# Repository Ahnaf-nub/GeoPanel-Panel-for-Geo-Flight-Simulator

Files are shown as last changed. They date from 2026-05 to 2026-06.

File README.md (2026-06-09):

Real-time flight telemetry display for GeoFS flight simulator using a Raspberry Pi Pico with TFT display, rotary encoder, and LED indicator.
Demo Link: https://youtu.be/hnZdgzygMNU

Use the Tampermonkey extension to add the geofs-telemetry-sender.js script. Follow the below for guidance:
Screenshot (104)
From Extensions click on Tampermonkey and click on "Create a new script".
Screenshot (106)
Then Paste the javascript code in here and save it!

## Bill of Materials (BOM)

| Part # | Component | Qty | Description |
|---|---|-----|---|
| 1 | Raspberry Pi Pico | 1 | Microcontroller
| 2 | ST7735 128x160 TFT Display | 1 | TFT Display | 1.8 inch |
| 3 | Push Button | 1 | User Input | Main button |
| 5 | Rotary Encoder | 1 | Parameter setting User Input | EC11 |

## Wiring Connections



### TFT Display (SPI)
- **MOSI** → GP27 (SPI TX)
- **SCK** → GP26 (SPI Clock)
- **CS** → GP21
- **DC** → GP19
- **RST** → GP18
- **VCC** → 3V3
- **GND** → GND

### LED
- **Onboard Green LED** → GP25

### Push Buttons
- **Main Button** → GP0
  
### Rotary Encoder
- **CLK (A)** → GP10
- **DT (B)** → GP11 
- **SW** → GP28 
- **+** → 3V3
- **GND** → GND

### Hardware Case

3D printed enclosure designed using fusion 360 (avionics_1.8inch.3mf) CAD model.

### System Architecture

```text
GeoFS Simulator → Tampermonkey Telemetry Script → Serial/Web Communication → Raspberry Pi Pico → TFT Display / LED / Inputs
```
There are 3 Tabs on the display:
1. FLT — Displays Flight data (IAS, ALT, VS, HDG, Pitch, Roll, etc.)
2. NAV — Displays Navigation information (Waypoint, Course, Bearing, Distance)
3. ADA — Displays Aircraft data & alerts (AOA, G-Load, Engine, Wind, Warnings)
   
### UI Design
Cockpit-style avionics layout
Typeface: Airbus B612 font used for all cockpit text rendering

## Dependencies

```ini
lib_deps = 
    adafruit/Adafruit ST7735 and ST7789 Library@^1.11.0
    adafruit/Adafruit NeoPixel
```

## Features

- Real-time flight data display (pitch, roll, heading, altitude, airspeed)
- G-load and stall/overspeed and other warning indicators
- Autopilot status display
- Rotary encoder for autpilot parameters adjustment
- LED status indicator
- System data visualization

## Future Plans

Currently working on adding potentiometer for thrust control. Also, will be adding a 1.28 inch round display to add radar system!

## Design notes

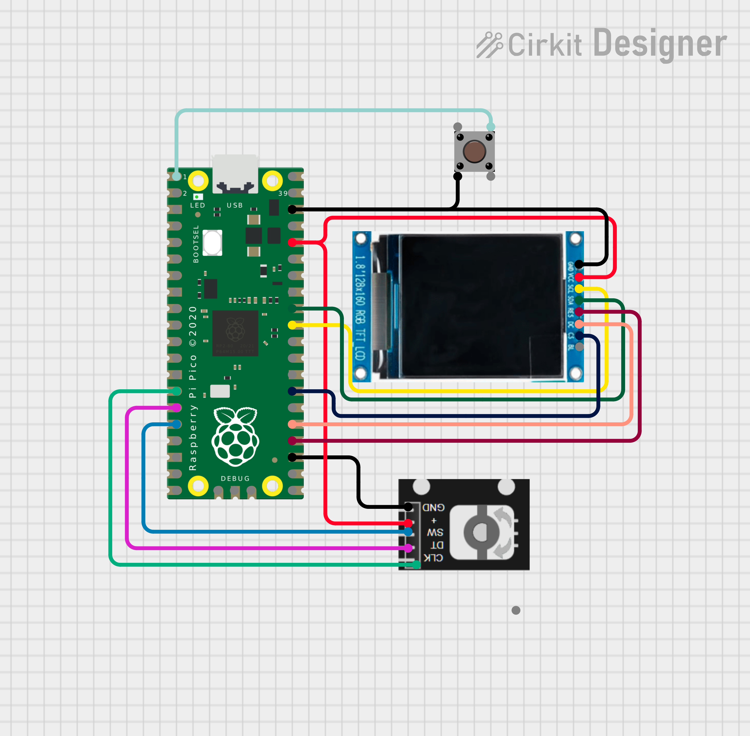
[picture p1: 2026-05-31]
circuit_image (1).png

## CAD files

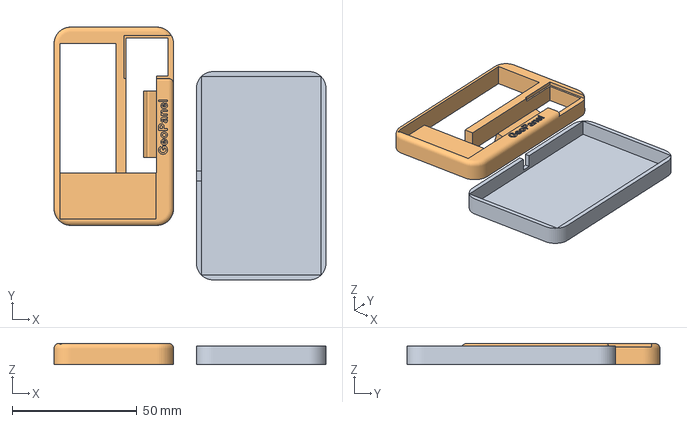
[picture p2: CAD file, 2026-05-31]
avionics_1.8inch.3mf
108.8 x 101.2 x 8.50 mm
avionics_1.8inch.stl_B
avionics_1.8inch.stl_A

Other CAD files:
avionics_1.8inch.stl

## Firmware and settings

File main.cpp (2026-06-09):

#include <SPI.h>
#include <Adafruit_GFX.h>
#include <Adafruit_ST7735.h>
#include <B612_Regular5pt7b.h>
#include <hardware/pio.h>
#include <hardware/timer.h>
#include <pico/multicore.h>
#include <pico/stdlib.h>
#include <freertos/FreeRTOS.h>
#include <freertos/task.h>

#define TFT_CS  21
#define TFT_DC  19
#define TFT_RST 18
#define TFT_SCK 26
#define TFT_MOSI 27
#define BTN_PIN  0
#define LED_PIN   25
#define POT_PIN   28  // Potentiometer — GPIO 28 (ADC2)

const int ENC_A = 10;
const int ENC_B = 11;
const int ENC_BTN = 12;

Adafruit_ST7735 tft(&SPI1, TFT_CS, TFT_DC, TFT_RST);

int dispW = 0;
int dispH = 0;

volatile float pitch=0, roll=0, hdg=0, alt=0, ias=0, vs=0;
const float PITCH_SCALE = 1.5f;
volatile float aoa=0, gLoad=1.0f, groundSpeed=0;
volatile float sp=0;  // mach number
volatile float engineRpmLeft=0, engineRpmRight=0;
volatile float windSpeedKt=0, windDirDeg=0;
volatile bool isStalling = false;
volatile bool isOverspeed = false;
volatile bool enginesOn = true;
volatile bool parkingBrake = false;
volatile float gearPosition  = 0.0f;
volatile float flapsPosition    = 0.0f;   // 0-1 normalised
volatile float spoilersPosition = 0.0f;   // 0-1 normalised
volatile char gpwsAlarm[32] = "";
volatile bool  groundContact = false;
volatile float haglFt = 0.0f;  // height above ground level (HAGL) in feet

// potentiometer part (still working!!)
volatile float potThrottle = 0.0f;  // 0.0-1.0 from pot
static int lastPotRaw = -1; 

volatile uint8_t activeTab   = 0;
volatile bool forceRedraw    = false;
volatile bool telemetryUpdated = false;
volatile bool apEnabled      = false;
volatile bool clearOnRedraw  = false;

const uint16_t COL_SKY    = 0x34BF;  // RGB565: ~#3399FF sky blue
const uint16_t COL_GROUND = 0xCA40;  // RGB565: ~#C8A000 warm sandy tan
const uint16_t COL_PANEL  = 0x2164;
const uint16_t COL_PANEL_EDGE = 0x7BEF;
const uint16_t COL_PANEL_DARK = 0x0861;
const uint16_t COL_MARK   = ST77XX_WHITE;
const uint16_t COL_ACCENT = 0x07FF;  // cyan
const uint16_t COL_LADDER_DIM = 0xC618;
const int TAPE_W = 27;  // width of airspeed and altitude tapes on sides of horizon tapes

bool inRoundedRect(int x, int y, int left, int top, int width, int height, int radius){
  int right = left + width - 1;
  int bottom = top + height - 1;

  if(x < left || x > right || y < top || y > bottom){
    return false;
  }

  int innerLeft = left + radius;
  int innerRight = right - radius;
  int innerTop = top + radius;
  int innerBottom = bottom - radius;

  if((x >= innerLeft && x <= innerRight) || (y >= innerTop && y <= innerBottom)){
    return true;
  }

  int dx = 0;
  int dy = 0;
  if(x < innerLeft) dx = innerLeft - x;
  else if(x > innerRight) dx = x - innerRight;
  if(y < innerTop) dy = innerTop - y;
  else if(y > innerBottom) dy = y - innerBottom;

  return (dx * dx + dy * dy) <= (radius * radius);
}

static inline uint32_t now_ms(){
  return (uint32_t)to_ms_since_boot(get_absolute_time());
}

bool checkButtonPress(int pin) {
  struct PinState { bool last; uint32_t edgeMs; };
  static PinState states[32] = {};
  PinState &s = states[pin];
  bool pressed = (digitalRead(pin) == LOW);
  uint32_t now = now_ms();
  bool fired = (!pressed && s.last && (now - s.edgeMs >= 25));
  if(pressed != s.last) s.edgeMs = now;
  s.last = pressed;
  return fired;
}

// Encoder selection mode: -1 = none, 0 = HDG, 1 = ALT, 2 = IAS

volatile int encMode   = -1;   // was: volatile int encMode   = -1;
volatile int targetHdg = 0;    // was: int targetHdg = 0;
volatile int targetAlt = 0;    // was: int targetAlt = 0;
volatile int targetIas = 0;   // knots
volatile int32_t encAccum  = 0; 
volatile uint8_t encLastAB = 0;
static const int8_t encQTable[16] = {
   0,+1,-1, 0,
  -1, 0, 0,+1,
  +1, 0, 0,-1,
   0,-1,+1, 0
};
struct repeating_timer encTimer;
bool encTimerCb(struct repeating_timer *t){
  uint8_t ab    = (gpio_get(ENC_A) << 1) | gpio_get(ENC_B);
  uint8_t idx2  = (encLastAB << 2) | ab;
  encLastAB     = ab;
  encAccum     += encQTable[idx2];
  return true;
}

volatile uint32_t apAckLockUntilMs = 0;

char buf[320]; int idx=0;
uint32_t lastTelemetryMs = 0;

void parseLine(char *s){
  // JS instances used:
  //  0 pitch  1 roll  2 hdg  3 alt  4 ias  5 vs  6 mach  7 aoa  8 gLoad  9 qnh
  //  11 groundSpeedKt  12 isStalling  13 isOverspeed
  // 14 enginesOn  15 parkingBrake  16-18 reserved(0)
  // 19 gpwsAlarm(str)  20 totalThrust  21 leftThrust  22 rightThrust
  // 23 engineRpm  24 engineRpmLeft  25 engineRpmRight
  // 26 gearPos  27 flapsPos  28 spoilersPos
  // 29 windSpeedKt  30 windDirDeg  31 haglFt  32 groundContact  33 apOn

  char *nl = strpbrk(s, "\r\n");
  if(nl) *nl = '\0';

  const int MAX_FIELDS = 40;
  char *fields[MAX_FIELDS] = {};
  int   nFields = 0;
  char *p = s;
  while(*p && nFields < MAX_FIELDS){
    fields[nFields++] = p;
    char *comma = strchr(p, ',');
    if(!comma) break;
    *comma = '\0';
    p = comma + 1;
  }

  if(nFields < 6) return;

  auto getF = [&](int i) -> float {
    if(i >= nFields || !fields[i] || !*fields[i]) return 0.0f;
    char *e = nullptr;
    float v = strtof(fields[i], &e);
    return (e != fields[i]) ? v : 0.0f;
  };
  auto getS = [&](int i, volatile char *dst, int dstLen)
  {
    if (i >= nFields || !fields[i])
    {
      dst[0] = '\0';
      return;
    }
    strncpy((char*)dst, fields[i], dstLen - 1);
    dst[dstLen - 1] = '\0';
  };

  isStalling  = false;
  isOverspeed = false;
  enginesOn   = true;
  parkingBrake = false;
  groundContact = false;

  pitch          = getF(0);
  roll           = getF(1);
  hdg            = getF(2);
  alt            = getF(3);
  ias            = getF(4);
  vs             = getF(5);
  sp = getF(6);   // mach number
  aoa            = getF(7);
  gLoad          = getF(8);
  groundSpeed    = getF(11);
  isStalling     = getF(12) > 0.5f;
  isOverspeed    = getF(13) > 0.5f;
  enginesOn      = getF(14) > 0.5f;
  parkingBrake   = getF(15) > 0.5f;
  getS(19, gpwsAlarm,    sizeof(gpwsAlarm));
  engineRpmLeft  = getF(24);
  engineRpmRight = getF(25);
  gearPosition     = getF(26);
  flapsPosition    = getF(27);
  spoilersPosition = getF(28);
  windSpeedKt      = getF(29);
  windDirDeg       = getF(30);
  haglFt           = getF(31);  // height above ground level (AGL) in feet
  groundContact    = getF(32) > 0.5f;

  if(now_ms() >= apAckLockUntilMs){
    apEnabled = getF(33) > 0.5f;
  }

  lastTelemetryMs = now_ms(); 
  telemetryUpdated = true; 

}

const uint32_t TELEMETRY_TIMEOUT_MS = 500;  // If no telemetry for 500ms, consider disconnected

void drawHorizonFast(float pitch, float roll, int x0, int y0, int w, int h){
  const int cornerRadius = 8;
  float rad = (-roll) * DEG_TO_RAD; 
  float sr  = sinf(rad), cr = cosf(rad);
  int   cx  = x0 + w / 2;
  int   cy  = y0 + h / 2;
  float pitchOffset = -pitch * PITCH_SCALE;

  for(int y = y0; y < y0 + h; y++){
    float dy = (float)(y - cy);

    int xLeft  = x0;
    int xRight = x0 + w;

    if(y < y0 + cornerRadius){
      int dy2 = y0 + cornerRadius - 1 - y;
      int dx  = (int)sqrtf((float)(cornerRadius * cornerRadius - dy2 * dy2));
      xLeft  = x0 + (cornerRadius - 1 - dx);
      xRight = x0 + w - (cornerRadius - 1 - dx);
    } else if(y >= y0 + h - cornerRadius){
      int dy2 = y - (y0 + h - cornerRadius);
      int dx  = (int)sqrtf((float)(cornerRadius * cornerRadius - dy2 * dy2));
      xLeft  = x0 + (cornerRadius - 1 - dx);
      xRight = x0 + w - (cornerRadius - 1 - dx);
    }
    int rowW = xRight - xLeft;
    if(rowW <= 0) continue;

    if(xLeft > x0)
      tft.drawFastHLine(x0, y, xLeft - x0, ST77XX_BLACK);
    if(xRight < x0 + w)
      tft.drawFastHLine(xRight, y, (x0 + w) - xRight, ST77XX_BLACK);

    if(fabsf(sr) < 0.015f){
      float f0 = dy * cr - pitchOffset;
      if(fabsf(f0) <= 1.2f)
        tft.drawFastHLine(xLeft, y, rowW, COL_MARK);
      else
        tft.drawFastHLine(xLeft, y, rowW, f0 < 0 ? COL_SKY : COL_GROUND);
      continue;
    }

    float xCrossF = (float)cx + (pitchOffset - dy * cr) / sr;
    int xi = (int)xCrossF;

    if(xi + 1 < xLeft){
      float f = (float)(xLeft - cx) * sr + dy * cr - pitchOffset;
      tft.drawFastHLine(xLeft, y, rowW, f < 0 ? COL_SKY : COL_GROUND);
      continue;
    }
    if(xi >= xRight){
      float f = (float)(xRight - 1 - cx) * sr + dy * cr - pitchOffset;
      tft.drawFastHLine(xLeft, y, rowW, f < 0 ? COL_SKY : COL_GROUND);
      continue;
    }

    float fLeft = (float)(xLeft - cx) * sr + dy * cr - pitchOffset;
    uint16_t leftCol  = (fLeft < 0) ? COL_SKY : COL_GROUND;
    uint16_t rightCol = (fLeft < 0) ? COL_GROUND : COL_SKY;

    int leftEnd = min(xi, xRight);
    if(leftEnd > xLeft)
      tft.drawFastHLine(xLeft, y, leftEnd - xLeft, leftCol);

    int sa = max(xi, xLeft);
    int sb = min(xi + 1, xRight - 1);
    if(sb >= sa)
      tft.drawFastHLine(sa, y, sb - sa + 1, COL_MARK);

    int rx = max(xi + 2, xLeft);
    if(rx <= xRight - 1)
      tft.drawFastHLine(rx, y, xRight - rx, rightCol);
  }
}

void drawPitchLadder(Adafruit_GFX &g, float pitch, float roll, int cx, int cy, int xLeft, int xRight, int yTop, int yBottom){
  float rad = (-roll) * DEG_TO_RAD;
  float s_r = sinf(rad), c_r = cosf(rad);   // s_r = -sin(roll), c_r = cos(roll)
  const int cornerRadius = 8;

  for(int p = -60; p <= 60; p += 10){
    if(p == 0) continue;
    
    float delta = (float)(pitch - p) * PITCH_SCALE;
    int px = cx + (int)(delta * (-s_r));
    int py = cy + (int)(delta * (-c_r));

    if(py < yTop - 8 || py > yBottom + 8) continue;

    int len = (abs(p) % 30 == 0) ? 28 : 16;
    uint16_t lineColor = (abs(p) % 30 == 0) ? COL_MARK : COL_LADDER_DIM;

    int x1 = px - (int)((len / 2) * c_r);
    int y1 = py + (int)((len / 2) * s_r);  
    int x2 = px + (int)((len / 2) * c_r);
    int y2 = py - (int)((len / 2) * s_r); 

    if(!inRoundedRect(px, py, xLeft, yTop, xRight - xLeft + 1, yBottom - yTop + 1, cornerRadius)){
      continue;
    }
    g.drawLine(x1, y1, x2, y2, lineColor);

    if(y1 >= yTop && y1 <= yBottom - 6 && x1 - 10 >= xLeft && x1 <= xRight){
      if(inRoundedRect(x1, y1, xLeft, yTop, xRight - xLeft + 1, yBottom - yTop + 1, cornerRadius)){
        g.setTextColor(lineColor); g.setCursor(x1 - 10, y1 + 4); g.print(abs(p));  // fixed Y
      }
    }
    if(y2 >= yTop && y2 <= yBottom - 6 && x2 + 2 >= xLeft && x2 + 12 <= xRight){
      if(inRoundedRect(x2, y2, xLeft, yTop, xRight - xLeft + 1, yBottom - yTop + 1, cornerRadius)){
        g.setTextColor(lineColor); g.setCursor(x2 + 2, y2 + 4); g.print(abs(p));  // fixed Y
      }
    }
  }
}

void drawRollScale(Adafruit_GFX &g, float roll, int cx, int arcY){
  const int R = 28;

  const int arcAngles[] = {-60,-45,-30,-20,-10,0,10,20,30,45,60};
  const int nAng = 11;
  for(int i = 0; i < nAng; i++){
    int a = arcAngles[i];
    float screenAngle = (float)(90 + a) * DEG_TO_RAD; // 0° bank → top
    float cs = cos(screenAngle), sn = sin(screenAngle);
    int tickLen = (a == 0 || abs(a) == 60) ? 7 : (abs(a) == 30 ? 5 : 3);
    uint16_t tcol = (a == 0 || abs(a) == 30 || abs(a) == 60) ? 0xFFFF : COL_ACCENT;
    int ox = cx + (int)(R * cs);
    int oy = arcY - (int)(R * sn);  // minus because screen-y is inverted
    int ix = cx + (int)((R - tickLen) * cs);
    int iy = arcY - (int)((R - tickLen) * sn);
    g.drawLine(ix, iy, ox, oy, tcol);
  }

  float screenAngle = (float)(90 - roll) * DEG_TO_RAD;
  float cs = cos(screenAngle), sn = sin(screenAngle);
  int tx  = cx + (int)((R - 1) * cs);
  int ty  = arcY - (int)((R - 1) * sn);
  int bx1 = cx + (int)((R - 6) * cos(screenAngle - 0.20f));
  int by1 = arcY - (int)((R - 6) * sin(screenAngle - 0.20f));
  int bx2 = cx + (int)((R - 6) * cos(screenAngle + 0.20f));
  int by2 = arcY - (int)((R - 6) * sin(screenAngle + 0.20f));
  g.fillTriangle(tx, ty, bx1, by1, bx2, by2, ST77XX_YELLOW);

  g.drawFastVLine(cx, arcY - R - 2, 5, 0xFFFF);
}

void drawAircraftSymbol(Adafruit_GFX &g, int cx, int cy);
void drawWindIndicator(int cx, int cy, int r, float windSpd, float windDir, float heading);
void drawAltitudeTape(int x, int yTop, int yBottom, int cy);
void drawAirspeedTape(int x, int yTop, int yBottom, int cy);
void drawRollScale(Adafruit_GFX &g, float roll, int cx, int arcY);
void drawPitchLadder(Adafruit_GFX &g, float pitch, float roll, int cx, int cy, int xLeft, int xRight, int yTop, int yBottom);
void formatAltitudeCompact(float altitudeFeet, char *out, size_t outSize);
void telemetryTask(void *pvParameters);
void inputTask(void *pvParameters);
void displayTask(void *pvParameters); 

void clearContentArea(){
  tft.fillRect(0, 12, dispW, dispH - 12, ST77XX_BLACK);
}

void drawTopInfoBar(int xLimit){
  const char *tabs[3] = {"FLT", "NAV", "ADA"};
  tft.fillRect(0, 0, xLimit, 12, COL_PANEL_DARK);
  tft.drawFastHLine(0, 12, xLimit, COL_PANEL_EDGE);
  tft.setTextSize(1);
  tft.setTextColor(COL_ACCENT, COL_PANEL_DARK);
  tft.setCursor(2, 9);  // fixed: top-left tab label
  tft.print(tabs[activeTab]);

  if(activeTab == 0){
    tft.setTextColor(COL_ACCENT, COL_PANEL_DARK);
    tft.setCursor(xLimit - 38, 9);
    tft.print("G: ");
    tft.print(gLoad, 1);
  } else if(activeTab == 2){
    const char *apStr = apEnabled ? "AP ON" : "AP OFF";
    uint16_t apColor = apEnabled ? 0x07E0 : 0xF800;
    tft.setTextColor(apColor, COL_PANEL_DARK);
    tft.setCursor(xLimit - 38, 9);
    tft.print(apStr);
  }
}

// HSI compass rose — rotates so that current heading is always abouth 12 o'clock.
void drawHeadingIndicator(int cx, int cy, int r, float hdg, int targetHdgVal){
  tft.drawCircle(cx, cy, r + 1, 0x4208);
  tft.drawCircle(cx, cy, r, 0x7BEF);
  
  for(int d = 0; d < 360; d += 5){
    float a   = (d - hdg - 90.0f) * DEG_TO_RAD;
    float ca  = cosf(a), sa = sinf(a);
    bool  maj = (d % 30 == 0);
    bool  med = (d % 10 == 0) && !maj;
    int   tlen = maj ? 8 : (med ? 4 : 2);
    uint16_t tcol = maj ? ST77XX_WHITE : 0x8410;

    int ox = cx + (int)(r * ca);
    int oy = cy + (int)(r * sa);
    int ix = cx + (int)((r - tlen) * ca);
    int iy = cy + (int)((r - tlen) * sa);
    tft.drawLine(ix, iy, ox, oy, tcol);

    if(maj){
      bool isCard = (d % 90 == 0);
      int  lx = cx + (int)((r - 16) * ca);
      int  ly = cy + (int)((r - 16) * sa);

      tft.setTextSize(1);
      if(isCard){
        const char *card = (d==0)?"N":(d==90)?"E":(d==180)?"S":"W";
        uint16_t cc = (d==0) ? 0xFFC0 : 0x07FF; 
        tft.setTextColor(cc, ST77XX_BLACK);
        tft.setCursor(lx - (int)(strlen(card)*3), ly+3);
        tft.print(card);
      } else {
        char lbl[3];
        snprintf(lbl, sizeof(lbl), "%02d", d/10);
        tft.setTextColor(0xFFFF, ST77XX_BLACK); 
        tft.setCursor(lx - (int)(strlen(lbl)*3), ly+3);
        tft.print(lbl);
      }
    }
  }

  tft.fillTriangle(cx-4, cy-r+9, cx+4, cy-r+9, cx, cy-r, 0xFFC0);  // Yellow reference
  tft.drawFastVLine(cx, cy-r-2, 3, 0xFFC0);

  if(encMode == 0 && targetHdgVal >= 0){
    float ba = (targetHdgVal - hdg - 90.0f) * DEG_TO_RAD;
    int bx = cx + (int)(r * cosf(ba));
    int by = cy + (int)(r * sinf(ba));
    int bix = cx + (int)((r-7) * cosf(ba));
    int biy = cy + (int)((r-7) * sinf(ba));
    float perp = ba + 1.5708f;
    int px = (int)(3.5f * cosf(perp)), py = (int)(3.5f * sinf(perp));
    tft.drawLine(bx+px, by+py, bix, biy, 0x07E0);
    tft.drawLine(bx-px, by-py, bix, biy, 0x07E0);
    tft.drawLine(bx+px, by+py, bx-px, by-py, 0x07E0);
  }

  tft.fillRect(cx-18, cy-9, 36, 18, ST77XX_BLACK);
  tft.drawRect(cx-18, cy-9, 36, 18, 0x07FF);
  tft.setTextSize(2);
  tft.setTextColor(ST77XX_CYAN, ST77XX_BLACK);
  char hdgStr[4];
  snprintf(hdgStr, sizeof(hdgStr), "%03d", ((int)hdg + 360) % 360);
  tft.setCursor(cx - 18, cy+5);  // 3 chars × 12px / 2 = 18px
  tft.print(hdgStr);
}

void drawNavPage(int viewW, int viewH, bool fullRedraw){
  if(fullRedraw) clearContentArea();

  const int topY  = 13;
  const int topH  = 12;
  const int botY  = viewH - 24;  // bottom strip starts 24px from bottom
  const int arcY0 = topY + topH + 1;   // arc area top
  const int arcY1 = botY - 1;          // arc area bottom

  tft.fillRect(0, topY, viewW, topH, COL_PANEL_DARK);
  tft.drawFastHLine(0, topY + topH, viewW, COL_PANEL_EDGE);

  char hdgStr[10], iasStr[10], altStr[10];
  snprintf(hdgStr, sizeof(hdgStr), "%03d", ((int)hdg + 360) % 360);
  snprintf(iasStr, sizeof(iasStr), "%d", (int)ias);
  snprintf(altStr, sizeof(altStr), "%d", (int)alt);
  tft.setTextSize(1);
  tft.setTextColor(0x07FF, COL_PANEL_DARK);
  tft.setCursor(2, topY + 9);
  tft.print(iasStr);
  tft.setTextColor(0xFFFF, COL_PANEL_DARK);
  tft.setCursor((viewW - (int)(strlen(hdgStr)*6)) / 2, topY + 9);
  tft.print(hdgStr);
  tft.setTextColor(0x07FF, COL_PANEL_DARK);
  tft.setCursor(viewW - 2 - (int)(strlen(altStr)*6), topY + 9);
  tft.print(altStr);

  tft.fillRect(0, botY, viewW, viewH - botY, COL_PANEL_DARK);
  tft.drawFastHLine(0, botY, viewW, COL_PANEL_EDGE);

  int cx = viewW / 2;
  int cy = arcY1;           
  int radius = arcY1 - arcY0; 
  if(radius < 20) radius = 20;

  tft.fillRect(0, arcY0, viewW, arcY1 - arcY0 + 1, ST77XX_BLACK);

  auto drawArc = [&](int r, uint16_t col, int step){
    int prevX = -1, prevY = -1;
    for(int deg = 0; deg <= 180; deg += step){
      float a = (float)deg * DEG_TO_RAD;
      int ox = cx + (int)roundf((float)r * cosf(a));
      int oy = cy - (int)roundf((float)r * sinf(a));
      if(oy < arcY0) oy = arcY0;
      if(ox < 0 || ox >= viewW) { prevX = -1; continue; }
      if(prevX >= 0 && abs(ox-prevX)<=2 && abs(oy-prevY)<=2)
        tft.drawLine(prevX, prevY, ox, oy, col);
      else
        tft.drawPixel(ox, oy, col);
      prevX = ox; prevY = oy;
    }
  };

  drawArc(radius,         0x7BEF, 1);           // outer — white-ish
  drawArc(radius * 2 / 3, 0x4208, 2);           // middle range ring
  drawArc(radius * 1 / 3, 0x2945, 2);           // inner range ring

  for(int d = 0; d < 360; d += 5){
    float relDeg = (float)((d - (int)hdg + 540) % 360) - 180.0f;
    if(relDeg < -90.0f || relDeg > 90.0f) continue;
    float a = (90.0f - relDeg) * DEG_TO_RAD;
    float ca = cosf(a), sa = sinf(a);
    int ox = cx + (int)roundf((float)radius * ca);
    int oy = cy - (int)roundf((float)radius * sa);
    if(oy > cy || oy < arcY0 || ox < 1 || ox > viewW - 2) continue;

    bool maj = (d % 30 == 0);
    bool med = (d % 10 == 0) && !maj;
    int tlen = maj ? 7 : (med ? 4 : 2);
    uint16_t tcol = maj ? ST77XX_WHITE : 0x7BEF;

    int ix = cx + (int)roundf((float)(radius - tlen) * ca);
    int iy = cy - (int)roundf((float)(radius - tlen) * sa);
    tft.drawLine(ix, iy, ox, oy, tcol);

    if(maj){
      int lx = cx + (int)roundf((float)(radius - 13) * ca);
      int ly = cy - (int)roundf((float)(radius - 13) * sa);
      if(ly < arcY0 + 2) continue;
      tft.setTextSize(1);
      if(d % 90 == 0){
        const char *card = (d==0)?"N":(d==90)?"E":(d==180)?"S":"W";
        uint16_t cc = (d==0) ? 0xFFC0 : 0x07FF;
        tft.setTextColor(cc, ST77XX_BLACK);
        tft.setCursor(lx - (int)(strlen(card)*3), ly + 3);
        tft.print(card);
      } else {
        char lbl[3];
        snprintf(lbl, sizeof(lbl), "%02d", d / 10);
        tft.setTextColor(0xFFFF, ST77XX_BLACK);
        tft.setCursor(lx - (int)(strlen(lbl)*3), ly + 3);
        tft.print(lbl);
      }
    }
  }

  tft.fillTriangle(cx-3, arcY0+6, cx+3, arcY0+6, cx, arcY0, 0xFFC0);

  tft.drawFastHLine(cx-7, cy-3, 14, 0xFFC0); 
  tft.drawFastVLine(cx,   cy-6,  4, 0xFFC0);  
  tft.drawFastHLine(cx-3, cy-1,  6, 0xFFC0);  

  float trackOffset = (groundSpeed > 1.0f) ? (aoa * 0.5f) : 0.0f;
  float trackA = (90.0f - trackOffset) * DEG_TO_RAD;
  int trx = cx + (int)((radius - 4) * cosf(trackA));
  int trY = cy - (int)((radius - 4) * sinf(trackA));
  if(trY <= cy) tft.drawLine(cx, cy, trx, trY, 0xF81F);

  if(encMode == 0 || apEnabled){
    int bugHdg = targetHdg;
    float bugRel = (float)((bugHdg - (int)hdg + 540) % 360) - 180.0f;
    if(bugRel >= -90.0f && bugRel <= 90.0f) {
      float ba = (90.0f - bugRel) * DEG_TO_RAD;  // same mapping as ticks
      int bx  = cx + (int)(radius * cosf(ba));
      int by  = cy - (int)(radius * sinf(ba));
      int bix = cx + (int)((radius-6) * cosf(ba));
      int biy = cy - (int)((radius-6) * sinf(ba));
      float perp = ba + 1.5708f;
      int px = (int)(3.0f*cosf(perp)), py = (int)(3.0f*sinf(perp));
      if(by <= cy){  // only draw if in upper half
        tft.drawLine(bx+px, by+py, bix, biy, 0x07E0);
        tft.drawLine(bx-px, by-py, bix, biy, 0x07E0);
        tft.drawLine(bx+px, by+py, bx-px, by-py, 0x07E0);
      }
    }
  }

  drawWindIndicator(18, botY + 12, 7, windSpeedKt, windDirDeg, hdg);
  tft.setTextSize(1);

  char vsLbl[10];
  snprintf(vsLbl,  sizeof(vsLbl),  "VS %+d", (int)vs);
  tft.setTextColor(0x07FF, COL_PANEL_DARK);
  tft.setCursor(90, botY + 16); tft.print(vsLbl);

  // AP target: show when the encoder is active, yellow colored text with label
  if(encMode >= 0){
    char tgtVal[10];
    const char *tgtLbl;
    if     (encMode == 0){ tgtLbl="HDG"; snprintf(tgtVal,sizeof(tgtVal),">%03d",targetHdg); }
    else if(encMode == 1){ tgtLbl="ALT"; snprintf(tgtVal,sizeof(tgtVal),">%d",  targetAlt); }
    else                 { tgtLbl="IAS"; snprintf(tgtVal,sizeof(tgtVal),">%d",  targetIas); }
    char apLine[16]; snprintf(apLine, sizeof(apLine), "%s%s", tgtLbl, tgtVal);
    tft.setTextColor(0xFFC0, COL_PANEL_DARK);
    tft.setCursor(90, botY + 24); tft.print(apLine);
  }
}
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
void loop(){
  vTaskDelay(pdMS_TO_TICKS(1000));
}
